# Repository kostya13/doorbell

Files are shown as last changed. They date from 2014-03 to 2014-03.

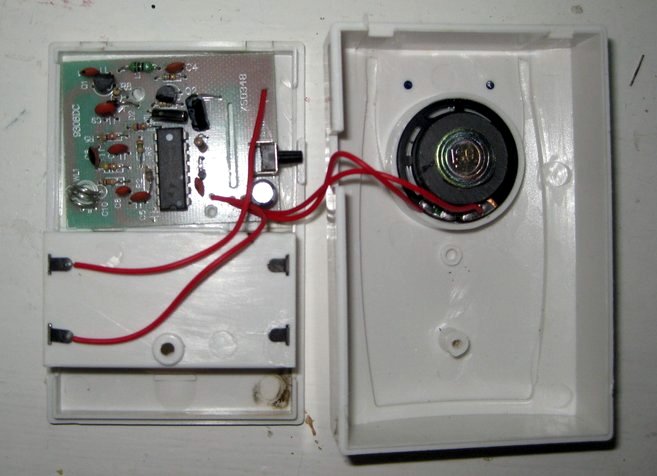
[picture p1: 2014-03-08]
images/view1.jpg

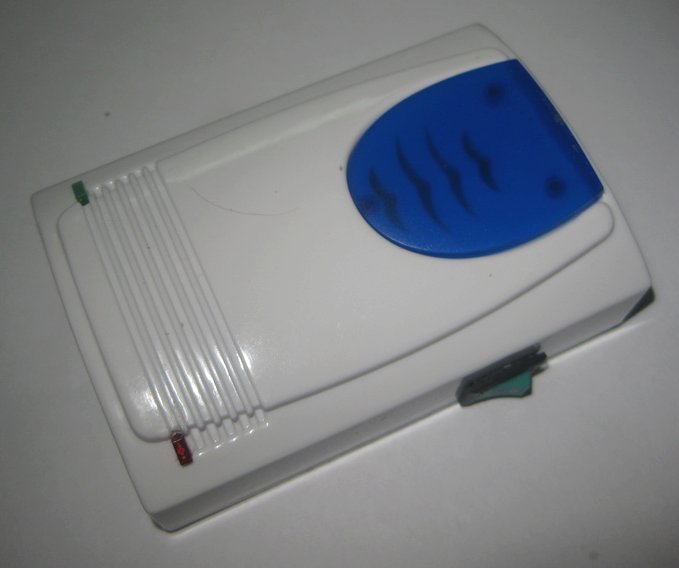
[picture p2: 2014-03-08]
images/view3.jpg

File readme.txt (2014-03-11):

Музыкальный дверной звонок

Автор: Костантин Ильяшенко <kx13@ya.ru> 

*Введение
Когда возникла необходимость установить дверной звонок было два варианта: купить готовый или сделать самому.

У готовых звонков был ряд недостатков:
- встроеные мелодии не отличаются качеством и разнообразием;
- нет регулятора громкости.

Но есть готовый корпус и в некоторых моделях радиокнопка.

Поэтому за основу я взял дешевый китайский звонок с радиокнопкой и поставил в него
синтезатор мелодии с регулированием громкости, блокированием включения и индикацией режима работы.

[view3.jpg]

В качестве мелодии можно загрузить большинство midi файлов.
Найти популярную мелодию в формате midi не представляет большой сложности. 

Чтобы сконвертировать midi в формат, пригодный для прошивки, в архиве проекта
есть программа Continy45 (автор Dmitry Dubrovenko http://www.dubrovenko.ru)

Несколько мелодий включено в архив прошивки.

За основу звукогенератора взята музыкальная шкатулка
http://elm-chan.org/works/mxb/report.html

Образец ее звучания:
http://elm-chan.org/works/mxb/mg.mpg

Данная прошивка может воспроизводить одновременно 6 каналов, поэтому получается полифония.
Звучание для дверного звонка, я считаю, очень неплохое. По крайней мере гораздо лучше, чем в магазинных звонках  и
можно самому выбрать приятную мелодию.

*Особенности звонка

- Очень простая схема.
- Большое количество доступных мелодий.
- Гибкая настройка режимов работы

Алгоритм работы музыкальной шкатулки был слегка переработан:
- Включение мелодии с помощью отдельной кнопки
- Можно заблокировать воспроизведение мелодии с помощью специального входа.
- Индикация блокировки мелодии на одном из выходов.
- Для увеличения громкости добавлен простой усилитель с регулятором громкости.

В качестве корпуса был использован радиозвонок с  питанием от батареек, поэтому батарейный отсек послужил отличным
местом для установки новой платы.

[view2.jpg]

Я установил контроллер в переходник на SOIC-DIP потомучто так удобнее  перепрошивать
во время отладки программы.

В качесте источника питания был применен слегка модернизированый б/п для зарядки сотового
телефона. В принципе, подойдет любой источник питания от 3 до 5В.

Из оригинального звонка микросхема звукогенератора была выпаяна, а сигнал от кнопки заводится на новую плату.

[view1.jpg]

Для индикации работы применяются два светодиода: зеленый - индикатор питания,  красный - блокировка звонка.

На дверь можно установить геркон и при открытии двери воспроизведение мелодии прекращается.
Так же на корпусе звонка есть переключатель для полной блокировки включения.

*Принципиальная схема

[scheme.png]

Схема достаточно простая. 

Если не нужна вся функциональность, то схему можно еще упростить.

Если не нужно автоматическое прерывание мелодии при откртой двери, то геркон SF1 можно не ставить, но тогда лучше
использовать более короткую мелодию. 

Переключатель SA1 - полной блокировки звонка можно тоже не ставить, но все-таки иногда удобно полностью отключить
звук звонка.

Если нет радиокнопки, то выход XS3 тоже не нужен. Т.к. это выход для питания радиомодуля

Усилитель звука сделан очень примитивным, на одном транзисторе, но для звонка этого достаточно.
Транзистор подойдет любой маломощный стуктуры n-p-n.

Переменный резистор R2, регулирующий громкость, можно сделать как подстроечным, оставив его внутри корпуса, 
так и вынести наружу корпуса, чтобы регулировать громкость по необходимости.

Если не нужна регулировка громкости, то R2 вообще можно не ставить, соединив выход PB1 контроллера с резистором R1.

Резистор R1 регулирует максимальную громкость, поэтому его номинал можно варировать примерно от 1 до 5кОм.

Громкость сильно зависит от самого динамика. Я проверял на двух похожих динамиках 0,25Вт, 8Ом. Если на одном
мелодию было еле слышно, то второй играл достаточно громко.

*Печатная плата

[pcb.png]

Сделана под размер батарейного отсека.

*Прошивка

Было внесено немного изменений в оригинальную прошивку музыкальной шкатулки, мои изменения прокомментироаны на русском языке.

Воспроизведение начинается, когда появляется высокий уровень на входе PB0.

Если появляется высокий уровень на входе PB2, но воспроизведение прекращается и блокируется до тех пор, пока на
входе PB2 не появится низкий уровень. 

Уровень входа PB2 копируется на выход PB3, которому подключен сигнальный светодиод.

Для правильной работы прошивки необходимо установить фьюзы:

[fuse.png]

галочка означает запрограммированый фьюз (значение 0).

Параметры для команды avrdude:
-U lfuse:w:0xd1:m -U hfuse:w:0xdd:m -U efuse:w:0xff:m 

Онлайн калькулятор фьюзов:
http://www.engbedded.com/fusecalc

Для удобной сборки и загрузки прошивки в проекте есть  Makefile.

Чтобы использовать другую мелодию, надо подключить в исходном файле asm-файл мелодии и пересобрать прошивку.
Прошивка подключается в метке "score:"

*Формат файлов

Схема и печатная плата разработана с помощью программы Kicad.
http://www.kicad-pcb.org/display/KICAD/Download

Прошивка собиралась с помощью ассемблера avra. 
Этот ассемблер совместим с оригинальным  ассемблером AVR, поэтому прошивка будет собираться в AVR Studio.
Так же ассемблер есть в комплекте Proteus7: папка Tools\AVRASM.

В архиве есть готовая прошивка и схемы в формате png.

*Редактирование мелодии
Одинаковые мелодии, взятые из разных источников могут звучать немного по разному, поэтому лучше скачать несколько
вариантов мелодий, и сделать несколько вариантов прошивок, из которых выбрать наиболее приятно звучащий
вариант. Так же в программе Continy45 есть ряд настроек меняющих звучание.

Можно предварительно отредактировать мелодию в midi, редакторе. Но это не так просто если не знаком
с таким родом программ. Зачастую проще сковертировать мелодию в формат прошивки, а в файле с мелодией
удалить часть мелодии. Этот метод не очень удобный но самый простой, если надо сократить длину мелодии.
Если сокращаете мелодию вручную, то надо смотреть, чтобы пара чисел перед EoS|en были близки по значению
к предыдущей ноте.
Например мелодия должна заканчиваться так:
119, 24, E4, H4|en, 0, 25, EoS|en
Т.е. в данном случае у ноты идет числа 24, затем 25 у метки конца мелодии.

И необходимо следить, чтобы не было такого предупреждения:
Warning : A .DB segment with an odd number of bytes is detected. A zero byte is added.
Если оно появилось, значит мелодия отредатирована не верно, где-то появился лишний байт.

*Примечания по количеству мелодий
Данная прошивка подразумевает воспроизведение одной мелодии.
Мне этого достаточно, поэтому я не стал усложнять прошивку.

Но несложно доработать прошивку таким образом, чтобы она воспроизводила несколько мелодий.
В Attiny45 можно записать 2-3 короткие мелодии. Если надо больше мелодий, можно применить
Attiny85 с 8кб флеш памяти. 

*Ссылки

Скачать проект:
https://bitbucket.org/kostya13/doorbell/downloads/doorbell.zip

Архив проекта:
https://bitbucket.org/kostya13/doorbell

Можно клонировать репозиторий Mercurial:
hg clone https://bitbucket.org/kostya13/doorbell

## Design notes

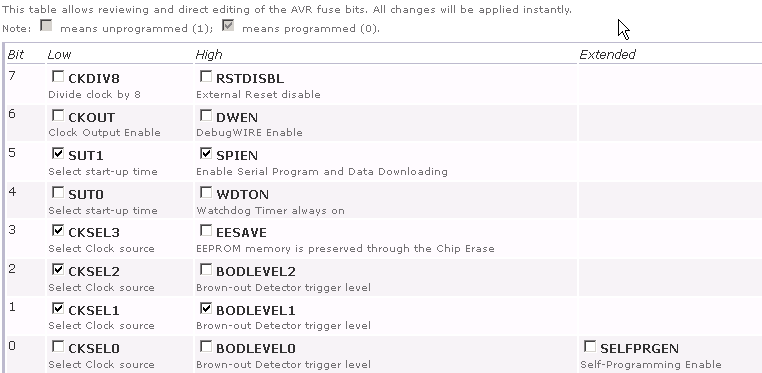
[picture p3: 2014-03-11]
images/fuses.png

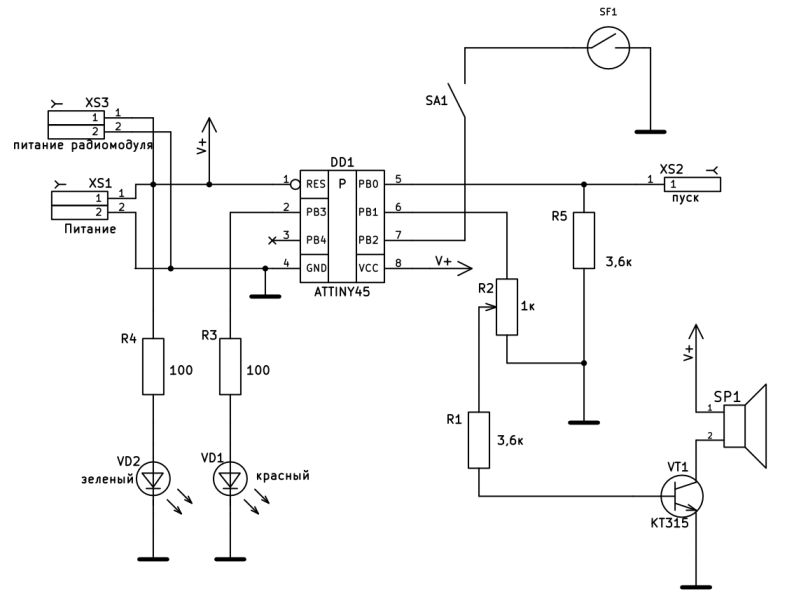
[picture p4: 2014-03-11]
images/scheme.png

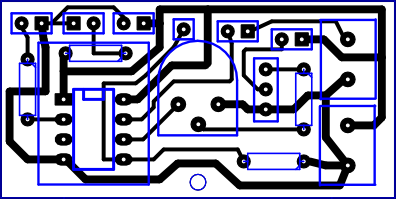
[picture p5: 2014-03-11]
images/pcb.png

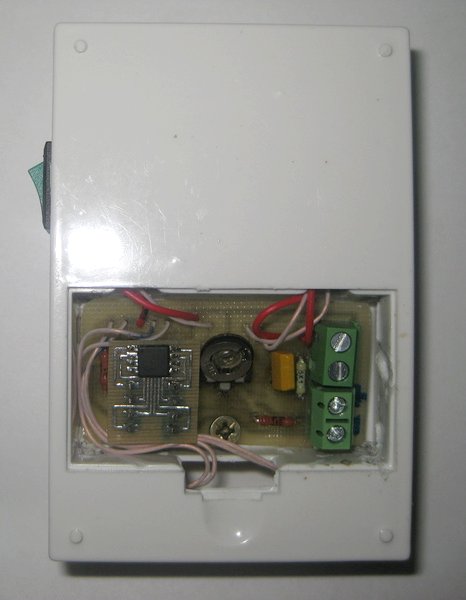
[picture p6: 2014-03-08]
images/view2.jpg

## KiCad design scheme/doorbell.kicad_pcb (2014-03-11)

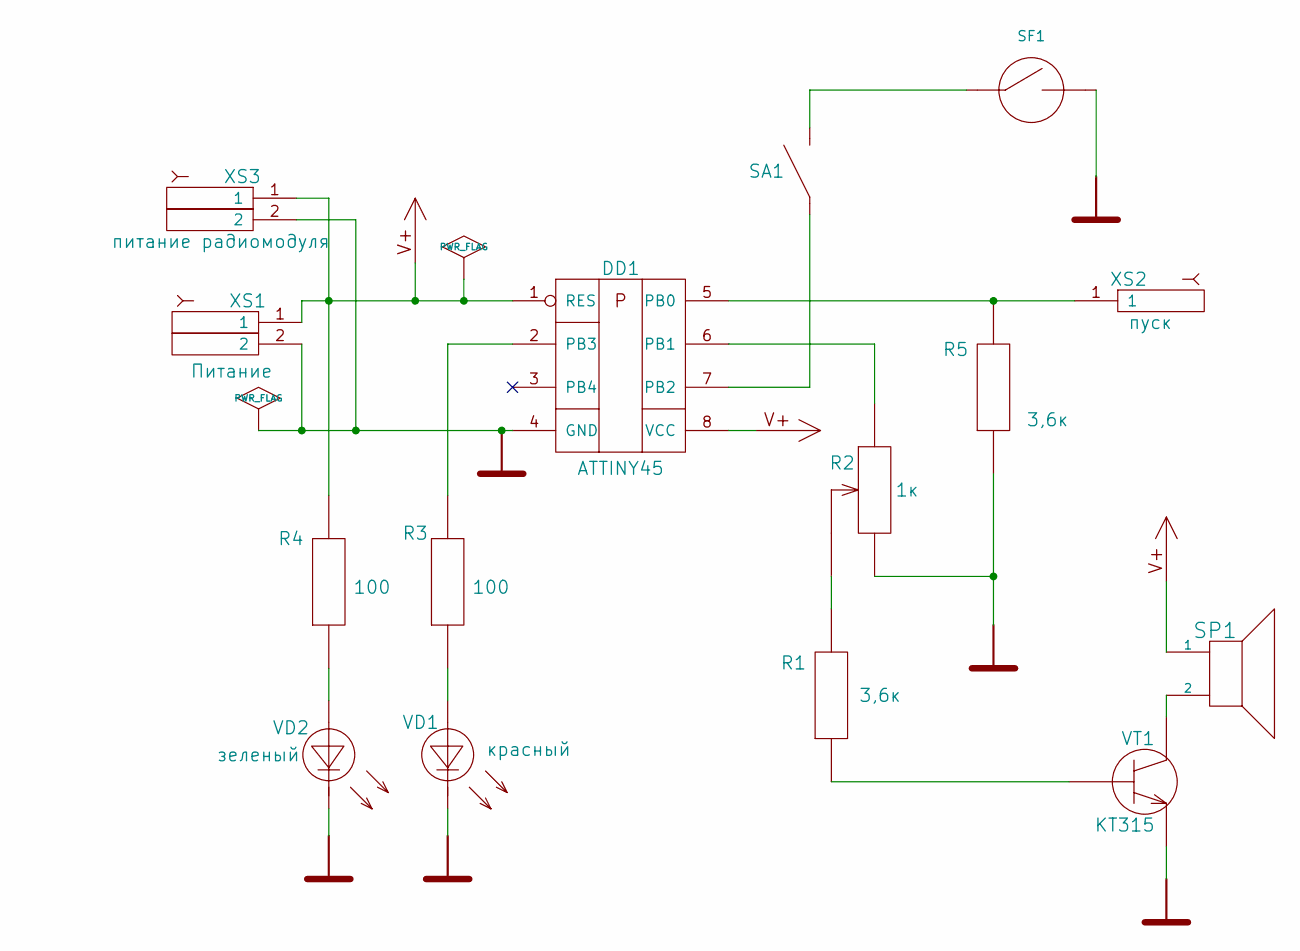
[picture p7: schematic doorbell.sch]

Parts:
DD1: ATTINY45
R1: 3,6к
R2: 1к
R3, R4: 100
R5: 3,6к
SA1: SA
SF1: SF
SP1: SPEAKER
VD1: красный
VD2: зеленый
VT1: КТ315
XS1: Питание
XS2: пуск
XS3: питание радиомодуля

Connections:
GND: DD1.4 (GND), R2.3, R5.1, SF1.1, VD1.1, VD2.1, VT1.3 (E), XS1.2, XS3.2
unnamed: R1.1, VT1.1 (B)
unnamed: R3.1, VD1.2
unnamed: R4.1, VD2.2
unnamed: DD1.2 (PB3), R3.2
unnamed: SP1.2, VT1.2 (C)
unnamed: DD1.6 (PB1), R2.1
unnamed: SA1.1, SF1.2
unnamed: R1.2, R2.2
unnamed: DD1.5 (PB0), R5.2, XS2.1
unnamed: DD1.7 (PB2), SA1.2
V+: DD1.1 (RES), DD1.8 (VCC), R4.2, SP1.1, XS1.1, XS3.1

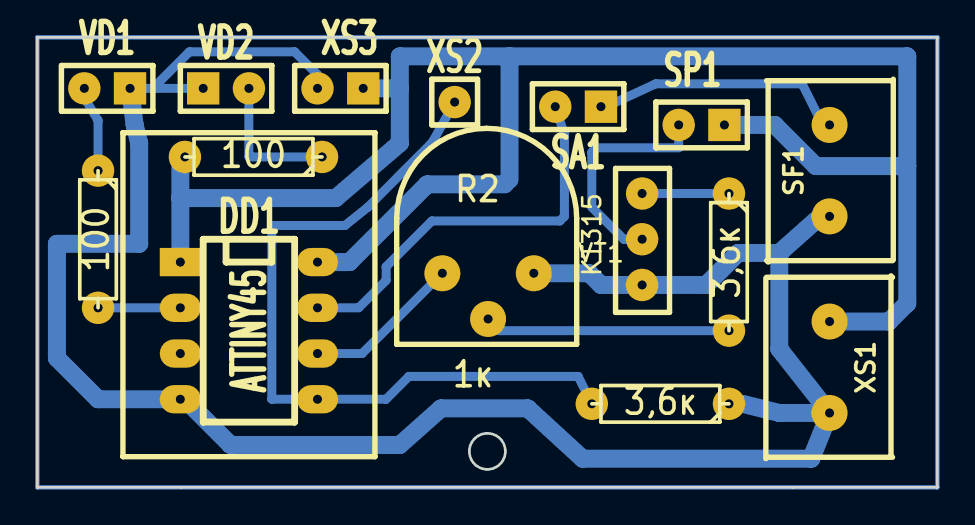
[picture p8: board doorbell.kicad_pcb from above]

Board: 2 copper layers, 50.0 x 25.0 mm, 15 parts (0 on the bottom side), 12 nets.

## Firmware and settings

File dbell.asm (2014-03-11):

;----------------------------------------------------------;
; Melody Generator  (C)ChaN, 2005
;
; Доработка для дверного звонка: Ильяшенко Константин <kx13@ya.ru>, 2014        

.include "tn45def.inc"  ;This is included in "Atmel AVR Studio"
.include "avr.inc"
.include "doorbell.inc"

.def  _0  = r15
.def  _Sreg = r14
.def  _Zreg = r12
.def  _Yreg = r10
.def  _TmrH = r9
.def  _TmrL = r8
.def  _TmrS = r7

.equ  N_NOTE  = 6

;----------------------------------------------------------;
; Work Area

.dseg
  .org  RAMTOP
NoteIdx:.byte 1 ; Note rotation index

Notes:  .byte (2+3+1+1+1+1)*N_NOTE
.equ  ns_freq = 0 ;Angular Speed
.equ  ns_rptr = 2 ;Wave table read pointer (16.8 fraction)
.equ  ns_lvl = 5  ;Level
.equ  ns_wrap = 6 ;Loop Flag
.equ  ns_loop = 7 ;Loop Count
.equ  ns_lp = 8 ;Level Pointer
.equ  nsize = 9 ;size of this structure


;----------------------------------------------------------;
; Program Code

.cseg
  ; Interrupt Vectors (ATtiny45)
  rjmp  reset   ; Reset
  rjmp  0   ; INT0
  rjmp  0   ; PCINT0
  rjmp  0   ; TC1_COMA
  rjmp  0   ; TC1_OVF
  rjmp  0   ; TC0_OVF
  rjmp  0   ; EE_RDY
  rjmp  0   ; ANA_COMP
  rjmp  0   ; ADC
  rjmp  0   ; TC1_COMB
  rjmp  isr_tc0_coma  ; TC0_COMA
; rjmp  0   ; TC0_COMB
; rjmp  0   ; WDT
; rjmp  0   ; USI_START
; rjmp  0   ; USI_OVF


;--------------------------------------------------------------------;
; Program Code

reset:

  clr _0
  ldiw  X, RAMTOP   ;Clear RAM
  ldi AL, 0 
  st  X+, _0
  dec AL    
  brne  PC-2     

; outi  OSCCAL, 172   ;Adjust OSCCAL if needed.

  outi  PORTB, 0b000100   ; Инициализация прота В
  outi  DDRB,  0b011010   ;/

  outi  PLLCSR, 0b00000110  ;Initialize TC1 in 250 kHz fast PWM mode.
  outi  TCCR1,  0b01100001  ;Connect TC1 to OC1A
  outi  GTCCR,  0b01100000  ;Connect TC1 to OC1B
 
  outi  OCR0A, 62   ;Initalize TC0 in 32 kHz interval timer.
  outi  TCCR0A, 0b00000010
  outi  TCCR0B, 0b00000010
  outi  TIMSK, (1<<OCIE0A)

start: 
  cli

wait:  ; главный цикл ожидания нажатия кнопки
  sbic PINB, 2 ; копируется состояние входа PB2 в выход PB3
  sbi PORTB, 3
  sbis PINB, 2 
  cbi PORTB, 3

  sbis PINB, 0 ; проверяется нажата ли клавиша звонка
  rjmp wait    ; если не нажата, ждем дальше

  sbic PINB, 2  ; здесь проверяется значения входа блокировки звонка
  rjmp wait


start_play:
  ldiw  Z, score*2
  clrw  _Tmr
  clr _TmrS
  sei

pl_next:
  lpmw  B, Z+
        rcall drv_decay
  cli
  cpw _Tmr, B
  sei
  brcs  PC-5

pl_note:
  lpm CL, Z+
  cpi CL, EoS
  breq  start

  sbic PINB, 2 ; Если обнаружен высокий уровень на входе блокирования
  rjmp start   ; перейти в режим ожидания. Мелодия остановится.


  mov AL, CL
  rcall note_on
  andi  CL, en
  breq  pl_note
  rjmp  pl_next



;--------------------------------------------------------------------;
; Note ON
;
;Call: AL[6:0] = key number

note_on:
  pushw Z

  mov ZL, AL
  lsl ZL
  clr ZH
  addiw Z, tbl_pitch*2
  lpmw  A, Z+

  lds YL, NoteIdx
  addi  YL, 9
  cpi YL, 9*N_NOTE
  brcs  PC+2
  clr YL
  sts NoteIdx, YL
  clr YH
  addiw Y, Notes

  ldiw  B, wt_attack*2
  cli
  stdw  Y+ns_freq, A
  stdw  Y+ns_rptr+1, B
  sei
  stdi  Y+ns_lvl, 255
  std Y+ns_wrap, AL
  std Y+ns_loop, _0
  std Y+ns_lp, _0

  popw  Z
  ret


;--------------------------------------------------------------------;
; Decay envelope generation

drv_decay:
  pushw Z
  ldiw  Y, Notes
dd_lp:
  ldd AL, Y+ns_wrap ;Has sustain loop not wrapped?
  ldi AH, 255   ;
  cp  AL, AH    ;
  breq  dd_nxt    ;/
  std Y+ns_wrap, AH ;Clear wrapped flag.
  ldd AL, Y+ns_loop
  inc AL
  cpi AL, 12
  brcs  PC+2
  ldi AL, 0
  std Y+ns_loop, AL
  brcs  dd_nxt
  ldd ZL, Y+ns_lp
  inc ZL
  breq  dd_nxt
  std Y+ns_lp, ZL
  clr ZH
  addiw Z, envelope*2
  lpm AL, Z
  std Y+ns_lvl, AL
dd_nxt: adiw  YL, 9
  cpi YL, low(Notes+nsize*N_NOTE)
  brne  dd_lp

  popw  Z
  ret



;--------------------------------------------------------------------;
; 32 kHz wave form synthesising interrupt


isr_tc0_coma:
  in  _Sreg, SREG   ;Save regs...
  movw  _Zreg, ZL   ;
  movw  _Yreg, YL   ;/

  ldiw  Y, Notes    ;Process all notes
  clrw  T2      ;Clear accumlator
tone_lp:
  ldd EH, Y+ns_rptr   ;Load wave table pointer
  lddw  Z, Y+ns_rptr+1    ;/
  lpm EL, Z     ;Get a sample
  lddw  T4, Y+ns_freq   ;Load angular speed
  add EH, T4L     ;Increase wave table ptr (next angle)
  adc ZL, T4H     ;
  adc ZH, _0      ;/
  cpi ZH, high(wt_end*2)  ;Repeat sustain area
  brcs  PC+4      ;
  subiw Z, (wt_end-wt_loop)*2 ;
  std Y+ns_wrap, _0   ;/
  std Y+ns_rptr, EH   ;Save wave table ptr
  stdw  Y+ns_rptr+1, Z    ;/
  ldd EH, Y+ns_lvl    ;Apply envelope curve
  MULT        ;/
  addw  T2, T0      ;Add the sample to accumlator
  adiw  YL, 9     ;Next note
  cpi YL, low(Notes+nsize*N_NOTE);
  brne  tone_lp     ;/

  asrw  T2      ;Divide it by 4
  asrw  T2      ;/
  ldiw  E, 253      ;Clip it between -255 to 253
  cpw T2, E     ;
  brlt  PC+2      ;
  movw  T2L, EL     ;
  ldiw  E, -255     ;
  cpw T2, E     ;
  brge  PC+2      ;
  movw  T2L, EL     ;/
  asrw  T2      ;Set it to PWM modulator
  ror T2H     ;
  mov EL, T2L     ;
  subi  EL, 0x80    ;
  mov EH, EL      ;
  com EH      ;
  sbrc  T2H, 7      ;
  inc EL      ;
  out OCR1A, EL   ;
  out OCR1B, EH   ;/

  sec       ;Increment sequense timer
  adc _TmrS, _0   ;
  adc _TmrL, _0   ;
  adc _TmrH, _0   ;/

  movw  ZL, _Zreg   ;Restore regs...
  movw  YL, _Yreg   ;
  out SREG, _Sreg   ;/

  reti



;--------------------------------------------------------------------;
; Score table
;--------------------------------------------------------------------;
; Здесь добавляется файл с мелодией
score:
.include "river-flows.asm"


;--------------------------------------------------------------------;
; Pitch number to angular speed conversion table
;--------------------------------------------------------------------;
;Since sustain area of wave table, a cycle of fundamental frequency, is sampled
;in 128 points, the base frequency becomes 32000/128 = 250 Hz. The wave table
;lookup pointer, 16.8 fraction, is increased every sample by these 8.8 fractional
;angular speed values.

tbl_pitch: ;  A     B     H     C    Cis    D    Dis    E     F    Fis    G    Gis 
  .dw  225,  239,  253,  268,  284,  301,  319,  338,  358,  379,  401,  425 ; 220Hz..
  .dw  451,  477,  506,  536,  568,  601,  637,  675,  715,  758,  803,  851 ; 440Hz..
  .dw  901,  955, 1011, 1072, 1135, 1203, 1274, 1350, 1430, 1515, 1606, 1701 ; 880Hz..
  .dw 1802, 1909, 2023, 2143, 2271, 2406, 2549, 2700, 2861, 3031, 3211, 3402 ; 1760Hz..
  .dw 3604, 3818, 4046, 4286, 4542, 4812, 5098, 5400         ; 3520Hz


;--------------------------------------------------------------------;
; Envelope Table
;--------------------------------------------------------------------;
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

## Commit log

2014-02-27 add stop/start buttons
2014-03-02 add kicad schemes
    [doorbell.kicad_pcb, doorbell.sch]
2014-03-03 next step
    [doorbell.sch]
2014-03-04 small changes
    [doorbell.kicad_pcb]
